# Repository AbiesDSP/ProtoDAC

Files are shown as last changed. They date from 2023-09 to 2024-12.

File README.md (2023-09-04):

# USB Prototype DAC

Uses a PSoC 5LP microcontroller as a USB to I2S bridge.

- USB Audio with Asynchronous feedback Synchronization
- Underflow/Overflow detection
- "EarSaver" muting if the device resets
- FreeRTOS kernel
- USB Serial Port for configuration.

# Installation and Building

Use PSoC Creator 4.4 to build the PSoC project. Make sure PSoC Creator has been installed and set up.

If there are any errors building, you may need to "update components" in the psoc creator project.

Clone and build the project
```bash
git clone https://github.com/AbiesDSP/ProtoDAC.git
cd ProtoDAC
```

Install the requirements (Optionally create a virtual environment first)

```bash
pip install -r requirements.txt
```

There are scripts to build the project, and update the firmware
on the device.

Update the firmware from a release

```bash
# unzip release
cd release_dir/ProtoDAC.x.x.x
python bootload.py
```

Build the project and update the device's firmware

```bash
python ./scripts/buildp.py
python ./scripts/bootload.py --dev
```

### View Log messages
```bash
python ./scripts/listen.py
```

### Using Virtual environments (Optional)
Set up a python virtual environment.

Windows:
```bash
python -m venv venv
. ./venv/Scripts/activate
```

Linux/Mac:
```bash
python -m venv venv
. ./venv/bin/activate
```

### Running Tests (Optional)

Use CMake/Python/VSCode to build and run tests. Catch2 test framework required for tests.

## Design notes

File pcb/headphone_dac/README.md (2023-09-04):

# headphone_dac_proto
Prototype USB DAC to test a Cypress PSoC 5lp as a USB to I2S Bridge, and analog output amplifier

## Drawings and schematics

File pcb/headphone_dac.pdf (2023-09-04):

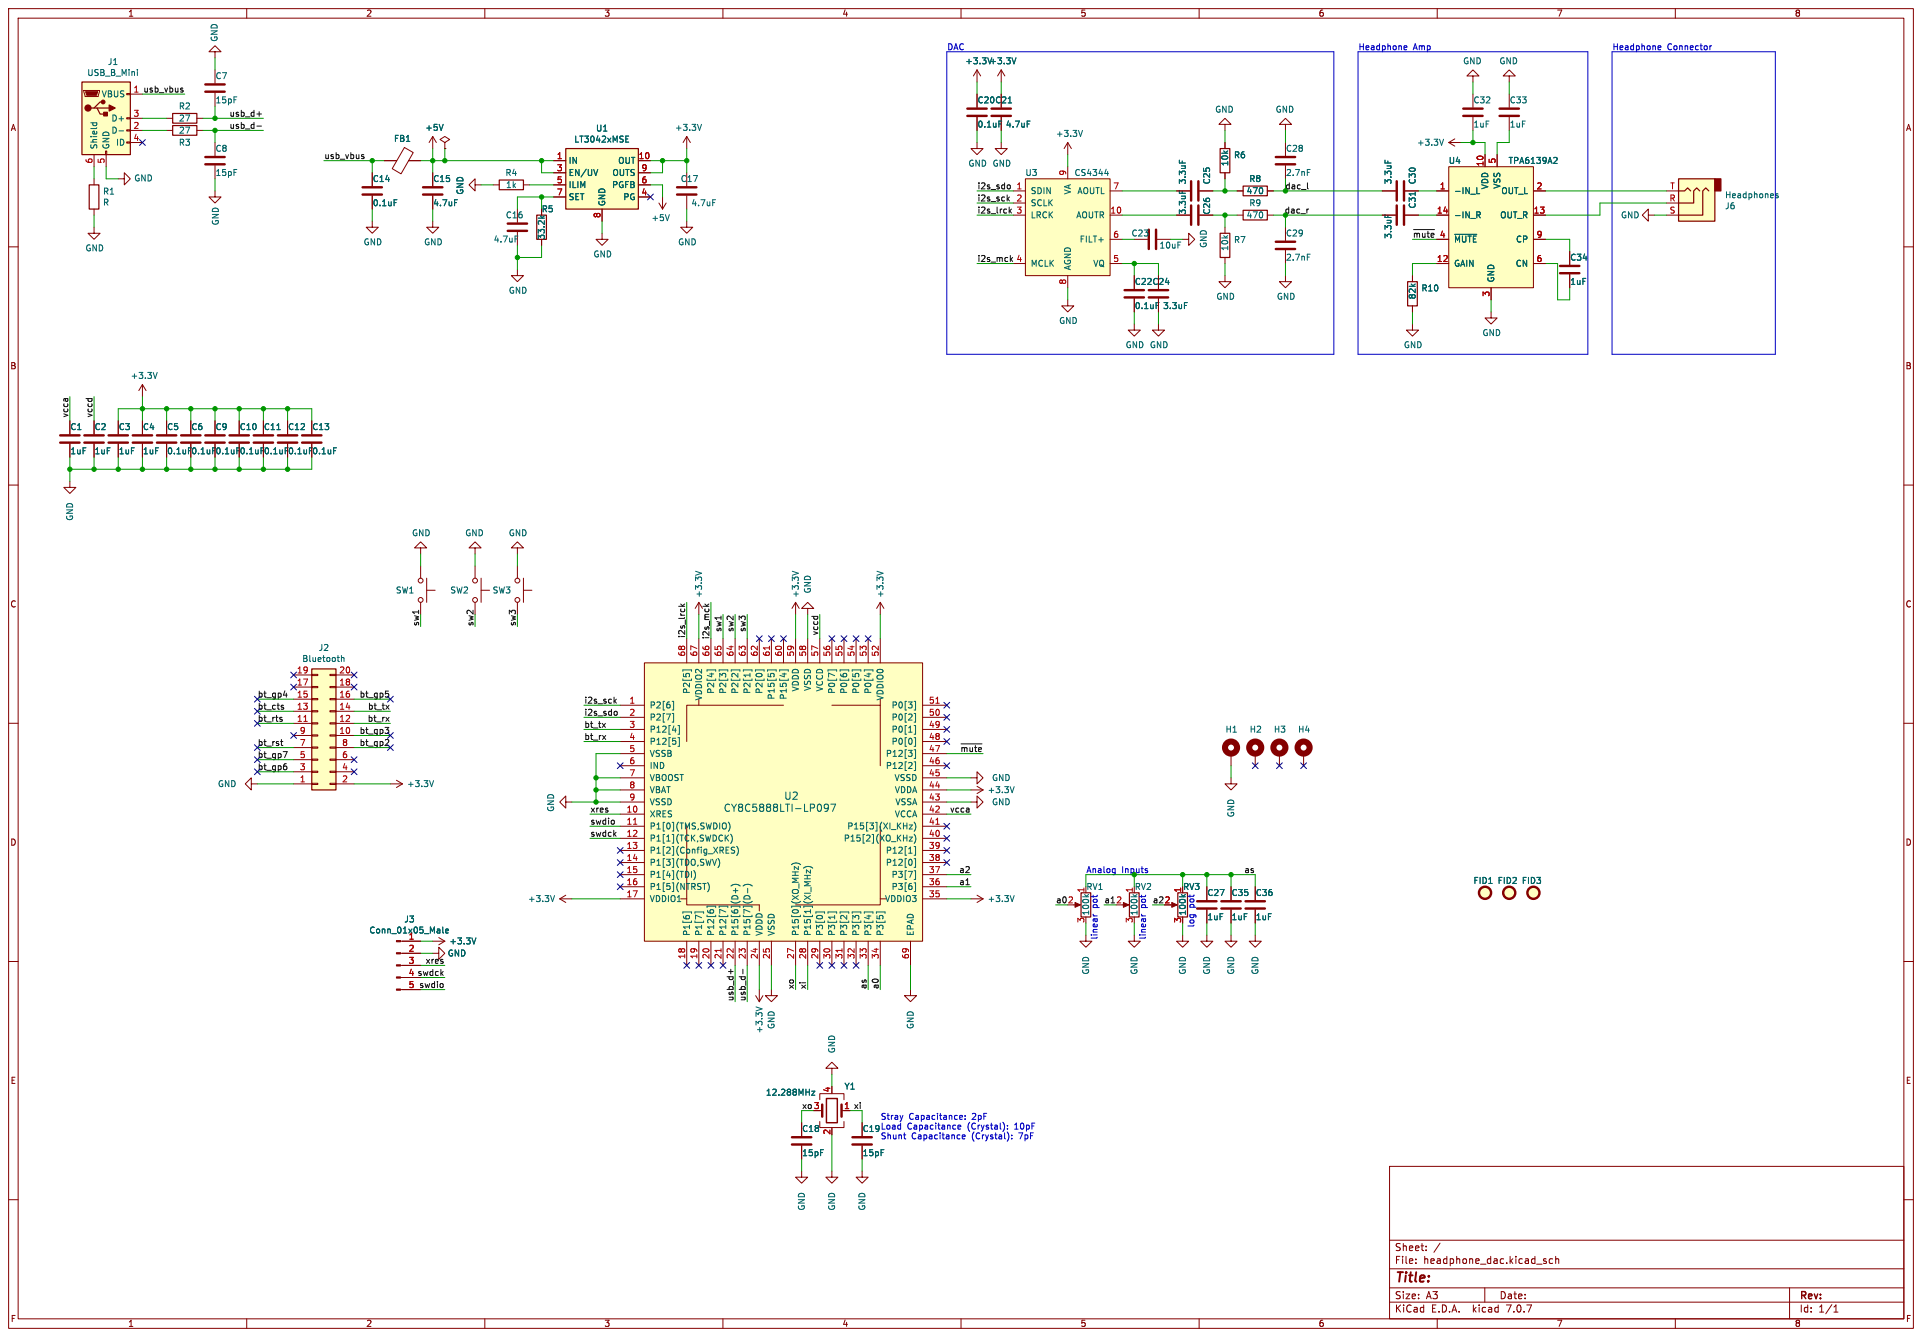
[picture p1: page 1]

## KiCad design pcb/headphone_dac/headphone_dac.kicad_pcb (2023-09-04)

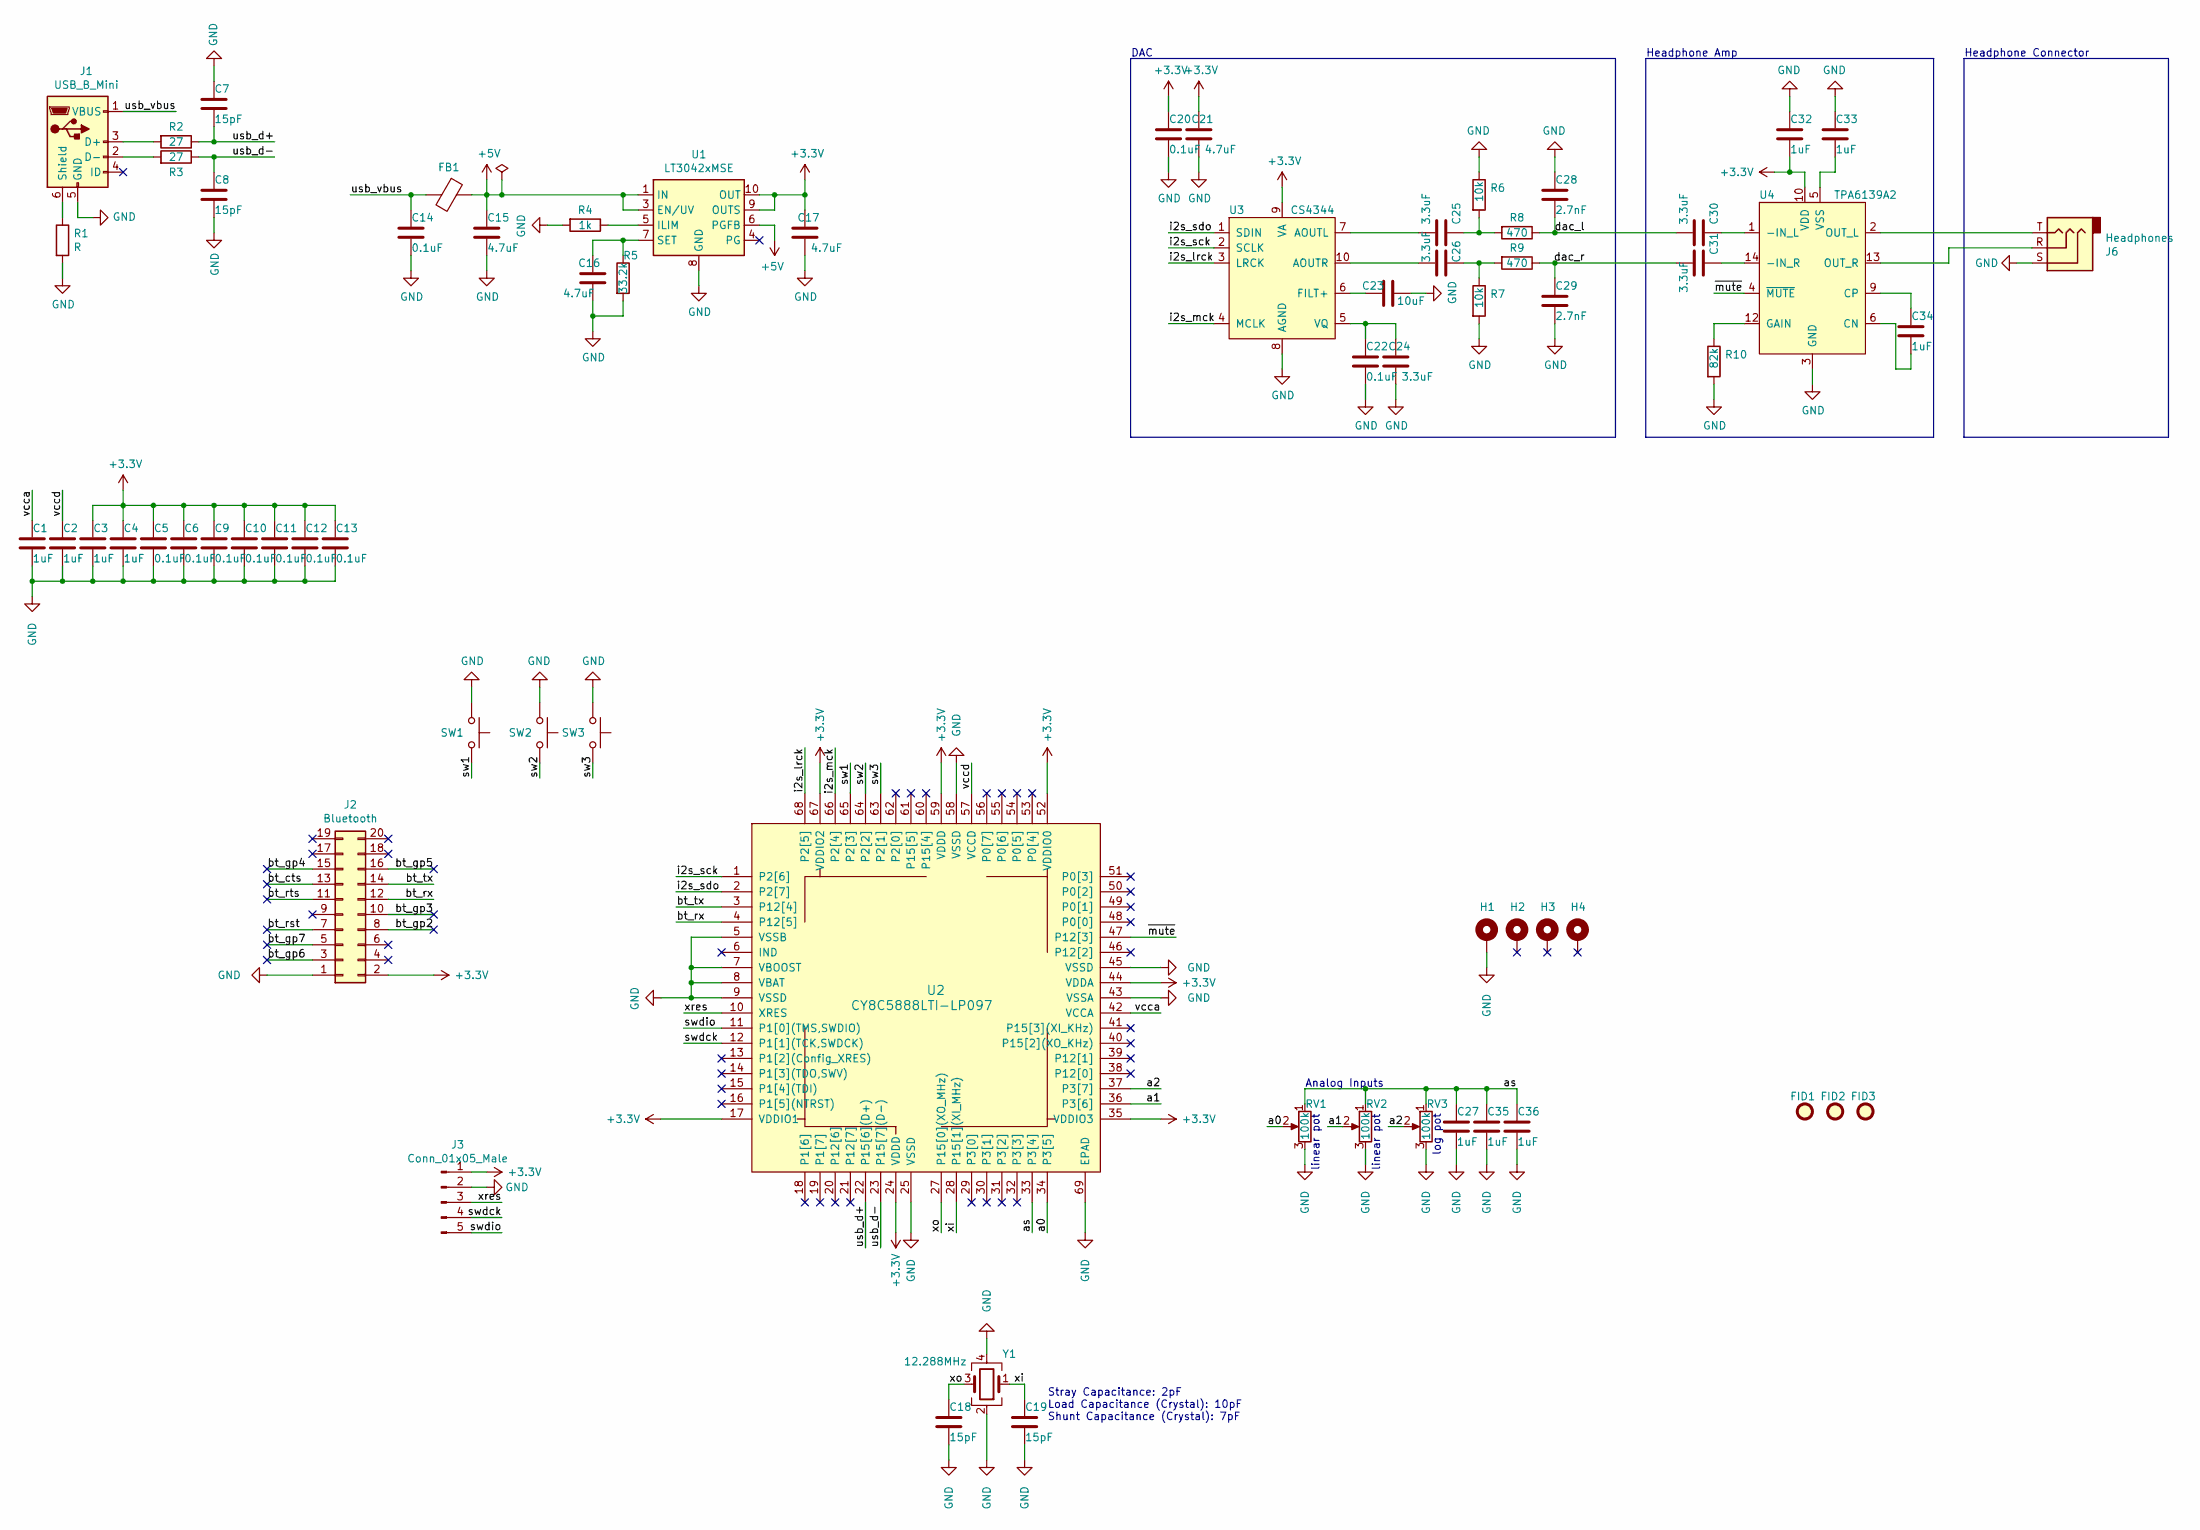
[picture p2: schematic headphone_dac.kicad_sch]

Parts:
C1, C2, C3, C4, C27, C32, C33, C34, C35, C36: 1uF; C_0603_1608Metric; Manufacturer Part Number C0603C105K3RAC7411; Mouser Part Number 80-C0603C105K3RLR
C5, C6, C9, C10, C11, C12, C13, C14, C20, C22: 0.1uF; C_0603_1608Metric; Manufacturer Part Number C0603C104K5RAC3121; Mouser Part Number 80-C603C104K5RAC3121
C7, C8, C18, C19: 15pF; C_0603_1608Metric; Manufacturer Part Number C0603C150K5RAC7867; Mouser Part Number 80-C0603C150K5RACTU
C15, C16, C17, C21: 4.7uF; C_0805_2012Metric; Manufacturer Part Number C0805C475K3RACTU; Mouser Part Number 80-C0805C475K3RACTU
C23: 10uF; C_0805_2012Metric; Manufacturer Part Number C0805C106K8RACAUTO; Mouser Part Number 80-C0805C106K8RAUTO
C24, C25, C26, C30, C31: 3.3uF; C_0805_2012Metric; Manufacturer Part Number CGA4J1X7R1E335K125AC; Mouser Part Number 810-CGA4J1X7R1E335K
C28, C29: 2.7nF; C_0603_1608Metric; Manufacturer Part Number C0603C272J5GACAUTO; Mouser Part Number 80-C0603C272J5GAUTO
FB1: L_0603_1608Metric; Manufacturer Part Number KMZ1608SHR601ATD25; Mouser Part Number 810-KMZ1608SHR601ATD
FID1, FID2, FID3: Fiducial_0.5mm_Mask1.5mm
H1: MountingHole_3mm_Pad_Via
H2, H3, H4: MountingHole_3mm_Pad
J1: USB_B_Mini; USB_Mini-B_Wuerth_65100516121_Horizontal; Manufacturer Part Number 65100516121; Mouser Part Number 710-65100516121
J2: Bluetooth; PinHeader_2x10_P2.54mm_Vertical; Manufacturer Part Number M20-9761046; Mouser Part Number 855-M20-9761046
J3: Conn_01x05_Male; PinHeader_1x05_P2.54mm_Vertical; Manufacturer Part Number 22-23-2051; Mouser Part Number 538-22-23-2051
J6: Headphones; Jack_3.5mm_CUI_SJ1-3535NG_Horizontal; Manufacturer Part Number SJ1-3535NG-GR; Mouser Part Number 490-SJ1-3535NG-GR
R1: R; R_0603_1608Metric
R2, R3: 27; R_0603_1608Metric; Manufacturer Part Number CRCW060327R0FKEAC; Mouser Part Number 71-CRCW060327R0FKEAC
R4: 1k; R_0603_1608Metric; Manufacturer Part Number ERJ-UP3D1001V; Mouser Part Number 667-ERJ-UP3D1001V
R5: 33.2k; R_0603_1608Metric; Manufacturer Part Number ERJ-PB3B3322V; Mouser Part Number 667-ERJ-PB3B3322V
R6, R7: 10k; R_0603_1608Metric; Manufacturer Part Number ERJ-UP3F1002V; Mouser Part Number 667-ERJ-UP3F1002V
R8, R9: 470; R_0603_1608Metric; Manufacturer Part Number ERJ-UP3F4700V; Mouser Part Number 667-ERJ-UP3F4700V
R10: 82k; R_Axial_DIN0207_L6.3mm_D2.5mm_P15.24mm_Horizontal; Manufacturer Part Number MFR-25FTE52-82K; Mouser Part Number 603-MFR-25FTE52-82K
RV1: 100k; Potentiometer_Bourns_PTV09A-1_Single_Vertical; Manufacturer Part Number PTV09A-4025U-A104; Mouser Part Number 652-PTV09A-4025UA104
RV2, RV3: 100k; Potentiometer_Bourns_PTV09A-1_Single_Vertical; Manufacturer Part Number PTV09A-4025F-B104; Mouser Part Number 652-PTV09A4025FB104
SW1, SW2, SW3: SW_PUSH_6mm_H13mm; Manufacturer Part Number SKHHDUA010; Mouser Part Number 688-SKHHDU
U1: LT3042xMSE; MSOP-10-1EP_3x3mm_P0.5mm_EP1.68x1.88mm_ThermalVias; Manufacturer Part Number LT3042EMSE#PBF; Mouser Part Number 584-LT3042EMSE#PBF
U2: CY8C5888LTI-LP097; QFN-68-1EP_8x8mm_P0.4mm_EP5.2x5.2mm_ThermalVias; Manufacturer Part Number CY8C5888LTI-LP097; Mouser Part Number 727-CY8C5888LTILP097
U3: CS4344; TSSOP-10_3x3mm_P0.5mm; Manufacturer Part Number CS4344-CZZR; Mouser Part Number 777-CS4344-CZZR
U4: TPA6139A2; TSSOP-14_4.4x5mm_P0.65mm; Manufacturer Part Number TPA6139A2PWR; Mouser Part Number 595-TPA6139A2PWR
Y1: 12.288MHz; Crystal_SMD_Abracon_ABM3B-4Pin_5.0x3.2mm; Manufacturer Part Number ABM3B-12.288MHZ-10-1-U-T; Mouser Part Number 815-ABM3B-12.288-T

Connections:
+3V3: C3.1, C4.1, C5.1, C6.1, C9.1, C10.1, C11.1, C12.1, C13.1, C17.1, C20.1, C21.1, C32.2, J2.2, J3.1, U1.9 (OUTS), U1.10 (OUT), U2.17 (VDDIO1), U2.24 (VDDD), U2.35 (VDDIO3), U2.44 (VDDA), U2.52 (VDDIO0), U2.59 (VDDD), U2.67 (VDDIO2), U3.9 (VA), U4.10 (VDD)
+5V: C15.1, FB1.1, U1.1 (IN), U1.2 (IN), U1.3 (EN/UV), U1.6 (PGFB)
/a0: RV1.2, U2.34 (P3[5])
/a1: RV2.2, U2.36 (P3[6])
/a2: RV3.2, U2.37 (P3[7])
/as: C27.1, C35.1, C36.1, RV1.1, RV2.1, RV3.1, U2.33 (P3[4])
/bt_cts: J2.13
/bt_gp2: J2.8
/bt_gp3: J2.10
/bt_gp4: J2.15
/bt_gp5: J2.16
/bt_gp6: J2.3
/bt_gp7: J2.5
/bt_rst: J2.7
/bt_rts: J2.11
/bt_rx: J2.12, U2.4 (P12[5])
/bt_tx: J2.14, U2.3 (P12[4])
/dac_l: C28.2, C30.2, R8.1
/dac_r: C29.1, C31.2, R9.1
/i2s_lrck: U2.68 (P2[5]), U3.3 (LRCK)
/i2s_mck: U2.66 (P2[4]), U3.4 (MCLK)
/i2s_sck: U2.1 (P2[6]), U3.2 (SCLK)
/i2s_sdo: U2.2 (P2[7]), U3.1 (SDIN)
/sw1: SW1.1, U2.65 (P2[3])
/sw2: SW2.2, U2.64 (P2[2])
/sw3: SW3.1, U2.63 (P2[1])
/swdck: J3.4, U2.12 (P1[1](TCK,SWDCK))
/swdio: J3.5, U2.11 (P1[0](TMS,SWDIO))
/usb_d+: C7.2, R2.1, U2.22 (P15[6](D+))
/usb_d-: C8.1, R3.1, U2.23 (P15[7](D-))
/usb_vbus: C14.1, FB1.2, J1.1 (VBUS)
/vcca: C1.1, U2.42 (VCCA)
/vccd: C2.1, U2.26 (VCCD), U2.57 (VCCD)
/xi: C19.1, U2.28 (P15[1](XI_MHz)), Y1.1
/xo: C18.1, U2.27 (P15[0](XO_MHz)), Y1.3
/xres: J3.3, U2.10 (XRES)
/~mute: U2.47 (P12[3]), U4.4 (~MUTE)
GND: C1.2, C2.2, C3.2, C4.2, C5.2, C6.2, C7.1, C8.2, C9.2, C10.2, C11.2, C12.2, C13.2, C14.2, C15.2, C16.2, C17.2, C18.2, C19.2, C20.2, C21.2, C22.2, C23.1, C24.2, C27.2, C28.1, C29.2, C32.1, C33.1, C35.2, C36.2, H1.1, J1.5 (GND), J2.1, J3.2, J6.S, R1.2, R4.2, R5.2, R6.1, R7.2, R10.2, RV1.3, RV2.3, RV3.3, SW1.2, SW2.1, SW3.2, U1.8 (GND), U1.11 (GND), U2.5 (VSSB), U2.7 (VBOOST), U2.8 (VBAT), U2.9 (VSSD), U2.25 (VSSD), U2.43 (VSSA), U2.45 (VSSD), U2.58 (VSSD), U2.69 (EPAD), U3.8 (AGND), U4.3 (GND), U4.11 (GND), Y1.2, Y1.4
unnamed: C16.1, R5.1, U1.7 (SET)
unnamed: C22.1, C24.1, U3.5 (VQ)
unnamed: C23.2, U3.6 (FILT+)
unnamed: C25.1, R6.2, R8.2
unnamed: C25.2, U3.7 (AOUTL)
unnamed: C26.1, R7.1, R9.2
unnamed: C26.2, U3.10 (AOUTR)
unnamed: C30.1, U4.1 (-IN_L)
unnamed: C31.1, U4.14 (-IN_R)
unnamed: C33.2, U4.5 (VSS)
unnamed: C34.1, U4.9 (CP)
unnamed: C34.2, U4.6 (CN)
unnamed: J1.2 (D-), R3.2
unnamed: J1.3 (D+), R2.2
unnamed: J1.6 (Shield), R1.1
unnamed: J6.R, U4.13 (OUT_R)
unnamed: J6.T, U4.2 (OUT_L)
unnamed: R4.1, U1.5 (ILIM)
unnamed: R10.1, U4.12 (GAIN)

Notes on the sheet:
Stray Capacitance: 2pF Load Capacitance (Crystal): 10pF Shunt Capacitance (Crystal): 7pF
DAC
linear pot
Headphone Connector
Headphone Amp
Analog Inputs
log pot

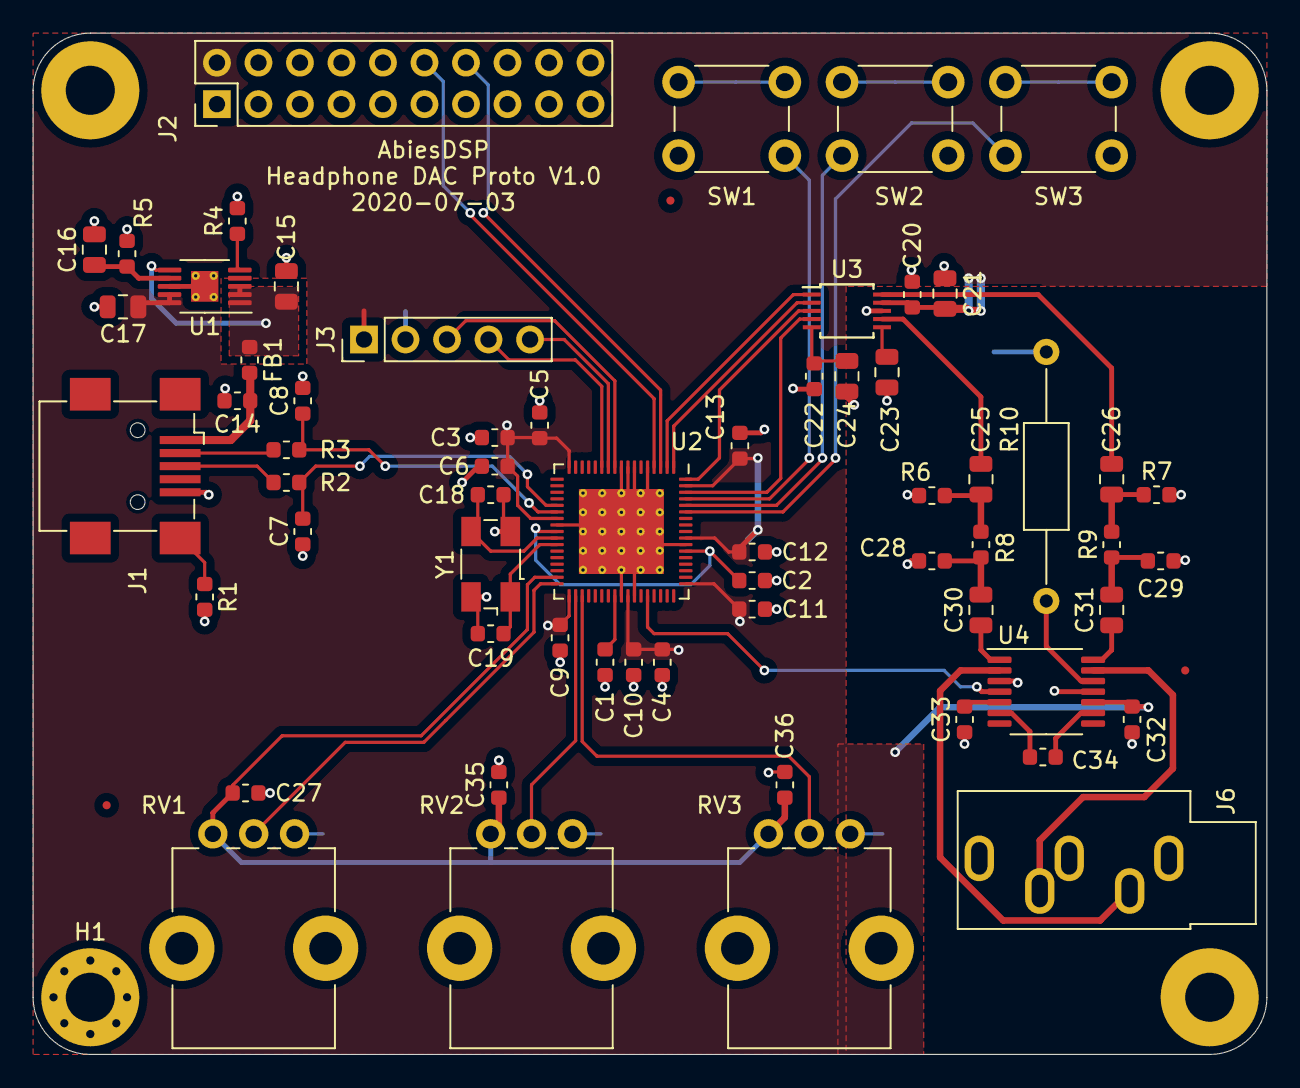
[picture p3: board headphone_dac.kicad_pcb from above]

Board: 2 copper layers, 75.5 x 62.5 mm, 69 parts (0 on the bottom side), 48 nets.

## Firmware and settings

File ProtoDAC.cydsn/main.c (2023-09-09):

#include "project_config.h"
#include "project.h"

#include "audio_tx.h"
#include "usb.h"
#include "sync.h"
#include "ear_saver.h"
#include "knobs.h"
#include "booter.h"
#include "avril.h"
#include "rtc.h"

#include "loggers.h"

static void prvHardwareSetup(void);
void SomeLogger(void *pvParameters);

int main(void)
{
#if !TEST_BUILD
    CyGlobalIntEnable;
#endif

    CyDelay(1);
    if (0 == (SwitchStatus_Read() & SW_BOOT))
    {
        Bootloadable_Load();
    }

    prvHardwareSetup();

    // Audio Transmit Tasks.
    TaskHandle_t AudioTxTask = NULL;
    xTaskCreate(AudioTxMonitor, "Audio Tx Monitor", LOG_MIN_STACK_SIZE, NULL, AUDIO_OUT_MONITOR_TASK_PRI, NULL);
    xTaskCreate(AudioTx, "Audio Tx", LOG_MIN_STACK_SIZE, usb_get_audio_out_ep_buf(), AUDIO_OUT_TASK_PRI, &AudioTxTask);
    xTaskCreate(AudioTxLogging, "Audio Tx Logging", LOG_MIN_STACK_SIZE, NULL, LOG_TASK_PRI, NULL);

    // USB Tasks
    usb_set_audio_output_task(AudioTxTask);
    xTaskCreate(USBConfigService, "USB Service Config", configMINIMAL_STACK_SIZE, NULL, USB_TASK_PRI, NULL);
    xTaskCreate(USBServiceAudioFeedbackEp, "USB Feedback", LOG_MIN_STACK_SIZE, NULL, USB_TASK_PRI, NULL);

    // USB Serial Port
    xTaskCreate(USBSerialTx, "USB Serial Tx", configMINIMAL_STACK_SIZE, NULL, SERIAL_TASK_PRI, NULL);
    xTaskCreate(USBSerialRx, "USB Serial Rx", configMINIMAL_STACK_SIZE, NULL, SERIAL_TASK_PRI, NULL);

    // USB Synchronization Monitor. Updates USB with new updates on the sample rate.
    xTaskCreate(SyncMonitor, "Sync Monitor", LOG_MIN_STACK_SIZE, NULL, SYNC_TASK_PRI, NULL);

    // Monitor for any error conditions that would cause unpleasant distortion, and automatically mute.
    xTaskCreate(EarSaver, "EarSaver", configMINIMAL_STACK_SIZE, NULL, EAR_SAVER_TASK_PRI, NULL);

    // Update the current state of the knobs.
    xTaskCreate(KnobsUpdate, "Knobs", configMINIMAL_STACK_SIZE, NULL, 1, NULL);

    // Bootload
    xTaskCreate(Booter, "Booter", configMINIMAL_STACK_SIZE, NULL, 1, NULL);

    // Real Time Clock. 1pps updates
    xTaskCreate(RTCUpdate, "RTC", configMINIMAL_STACK_SIZE, NULL, 1, NULL);

    // xTaskCreate(SomeLogger, "Some Logger", 512, NULL, 1, NULL);

    vTaskStartScheduler();

    for (ever)
    {
    }
}

void prvHardwareSetup(void)
{
    /* Port layer functions that need to be copied into the vector table. */
    extern void xPortPendSVHandler(void);
    extern void xPortSysTickHandler(void);
    extern void vPortSVCHandler(void);
    extern cyisraddress CyRamVectors[];

    /* Install the OS Interrupt Handlers. */
    CyRamVectors[11] = (cyisraddress)vPortSVCHandler;
    CyRamVectors[14] = (cyisraddress)xPortPendSVHandler;
    CyRamVectors[15] = (cyisraddress)xPortSysTickHandler;

    /* Start-up the peripherals. */
    rtc_init();
    audio_tx_init();
    usb_audio_init();
    usb_serial_init();
    sync_init();
    knobs_init();
    avril_init();
    avril_register(2048, &RTCIface, 4);
    avril_register(16384, &BooterIface, 4);

    // Configure serial logger
    logger_init(&main_log, &usb_serial_log_handler, NULL, NULL, NULL);

    main_log.level = GLOBAL_LOG_LEVEL;
}

void SomeLogger(void *pvParameters)
{
    (void)pvParameters;

    const TickType_t log_interval = pdMS_TO_TICKS(500);

    for (ever)
    {
        vTaskDelay(log_interval);
        log_debug(&main_log, "Hello, World!\n");
    }
}

/*---------------------------------------------------------------------------*/
void vApplicationStackOverflowHook(TaskHandle_t pxTask, char *pcTaskName)
{
    (void)pxTask;
    (void)pcTaskName;
    /* The stack space has been exceeded for a task, considering allocating more. */
    taskDISABLE_INTERRUPTS();
    for (;;)
        ;
}
/*---------------------------------------------------------------------------*/

void vApplicationMallocFailedHook(void)
{
    /* The heap space has been exceeded. */
    taskDISABLE_INTERRUPTS();
    for (;;)
        ;
}
/*---------------------------------------------------------------------------*/

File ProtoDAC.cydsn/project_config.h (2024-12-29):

#pragma once
#include "FreeRTOS.h"
#include "task.h"
#include "queue.h"
#include "semphr.h"
#include "portable.h"
#include "log_level.h"
#include <cytypes.h>

// Enable processing data before transmitting.
#define ENABLE_PROC 1

// Switches
#define SW_BOOT 0x8
#define SW_SOMESWITCH 0x4
#define SW_MUTE 0x2

// Stack sizes
#define LOG_MIN_STACK_SIZE 512

// Task priorities
#define AUDIO_OUT_TASK_PRI 5
#define AUDIO_OUT_MONITOR_TASK_PRI 4
#define USB_TASK_PRI 3
#define SYNC_TASK_PRI 2
#define SERIAL_TASK_PRI 2
#define EAR_SAVER_TASK_PRI 2
#define LOG_TASK_PRI 1

// Initial sample rate
#define AUDIO_SAMPLE_RATE 48000

// Enough for 96kHz
#define USB_AUDIO_EP_BUF_SIZE 588
#define USB_CONFIG_SERVICE_MAX_WAIT 100
#define USB_FEEDBACK_MAX_WAIT 150
#define USB_SERIAL_EP_BUF_SIZE 64

// USB Interface Configuration
#define USBFS_DEVICE 0
#define USB_ALT_INVALID 0xFF

#define USB_AUDIO_CTL_IFACE 0
#define USB_AUDIO_CTL_EP 5

#define USB_AUDIO_OUT_IFACE 1
#define USB_AUDIO_OUT_EP 1
#define USB_AUDIO_OUT_N_ALT 2
#define USB_AUDIO_OUT_ALT_ZEROBW 0
#define USB_AUDIO_OUT_ALT_STREAM 1

#define USB_AUDIO_FB_EP 3
// #define USB_AUDIO_IN_EP 2

#define USB_AUDIO_HID_IFACE 2
#define USB_AUDIO_HID_EP 4

//
// USB Serial Port
//
#define USB_SERIAL_CTL_IFACE 3
#define SERIAL_CTL_EP 6

#define USB_SERIAL_DATA_IFACE 4
#define USB_SERIAL_TX_EP 7
#define USB_SERIAL_RX_EP 8

#define USB_SERIAL_TX_BUF_SIZE 256

// USB Synchronization
#define SYNC_WINDOW_SIZE 128
#define SYNC_N_WINDOWS 16
#define SYNC_SHIFT 5 // log2(SYNC_N_WINDOWS * SYNC_WINDOW_SIZE / 64). 3 for 96kHz
#define SYNC_START_DELAY 200
#define SYNC_MAX_WAIT 150

// Audio transmit buffer
#define AUDIO_TX_TRANSFER_SIZE 588
#define AUDIO_TX_N_TDS 16
#define AUDIO_TX_BUF_SIZE (AUDIO_TX_TRANSFER_SIZE * AUDIO_TX_N_TDS)
// Turn on audio when it's half full
#define AUDIO_TX_ACTIVE_LIMIT ((AUDIO_TX_TRANSFER_SIZE * AUDIO_TX_N_TDS) >> 1)

#define AUDIO_TX_OVERFLOW_BLOCKS 4
#define AUDIO_TX_OVERFLOW_LIMIT (AUDIO_TX_BUF_SIZE - AUDIO_TX_TRANSFER_SIZE * AUDIO_TX_OVERFLOW_BLOCKS)
#define AUDIO_TX_UNDERFLOW_LIMIT (AUDIO_TX_TRANSFER_SIZE * AUDIO_TX_OVERFLOW_BLOCKS)

#define AUDIO_TX_TX_MAX_WAIT 1
#define AUDIO_TX_MONITOR_MAX_WAIT 1
#define AUDIO_TX_LOGGING_INTERVAL 2000
#define AUDIO_TX_DELTA_QUEUE_SIZE 8
#define AUDIO_TX_MAX_BS_TDS ((AUDIO_TX_BUF_SIZE + DMA_MAX_TRANSFER_SIZE - 1) / DMA_MAX_TRANSFER_SIZE) // Sufficient number of tds for entire memory.

// Ear Saver Config
#define EAR_SAVER_STARTUP_DELAY 100
#define EAR_SAVER_RESET_INTERVAL 2

// Logging
#define GLOBAL_LOG_LEVEL LOG_INFO
#define LOG_MESSAGE_BUF_SIZE 256

//
#define DMA_MAX_TRANSFER_SIZE 4095

#define ever \
    ;        \
    ;

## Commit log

2023-08-19 Setting up project. Still makes horrible static noises
    [main.c, psoc_creator.py]
2023-09-04 Dev (#2)
    * It works?
    * Still working?. Adding processing.
    * Everything working great.
    * Add pcb project
    * Update readme.
    * Compile with optimizations
    * Fix sync clock issues.
    * It's working but I'm still going to tinker.
    * Refactor and add serial rx
    * More tinkering
    * Add freertos
    * Fixed freertos...needed to lower the priority of external ISRs like usb
    * Fix buffer issues...Dont return in a task lol. Add ear saver muter.
    * Do not modify variables in two different processes.
    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
    [headphone_dac-B_Cu.gbr, headphone_dac-B_Mask.gbr, headphone_dac-Edge_Cuts.gbr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]
2023-09-09 The delay at the start of the sync task caused the sync_counter to not work on startup
    [avril.py, main.c, project_config.h]
2025-06-29 Uv updates (#6)
    * Set up uv, fix dependencies
    * remove unused requirements.txt
    [bootload.py]
